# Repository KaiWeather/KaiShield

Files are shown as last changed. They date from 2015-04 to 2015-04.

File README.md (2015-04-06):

# KaiShield
Arduino Shield with capabilities of being a independent entity with a XBee.

PCB files for KaiShield for Arduino

Format is EagleCAD schematic and board layout

Designed by Kai Weather.  
Creative Commons Attribution, Share-Alike license, check license.txt for more information
All text above must be included in any redistribution

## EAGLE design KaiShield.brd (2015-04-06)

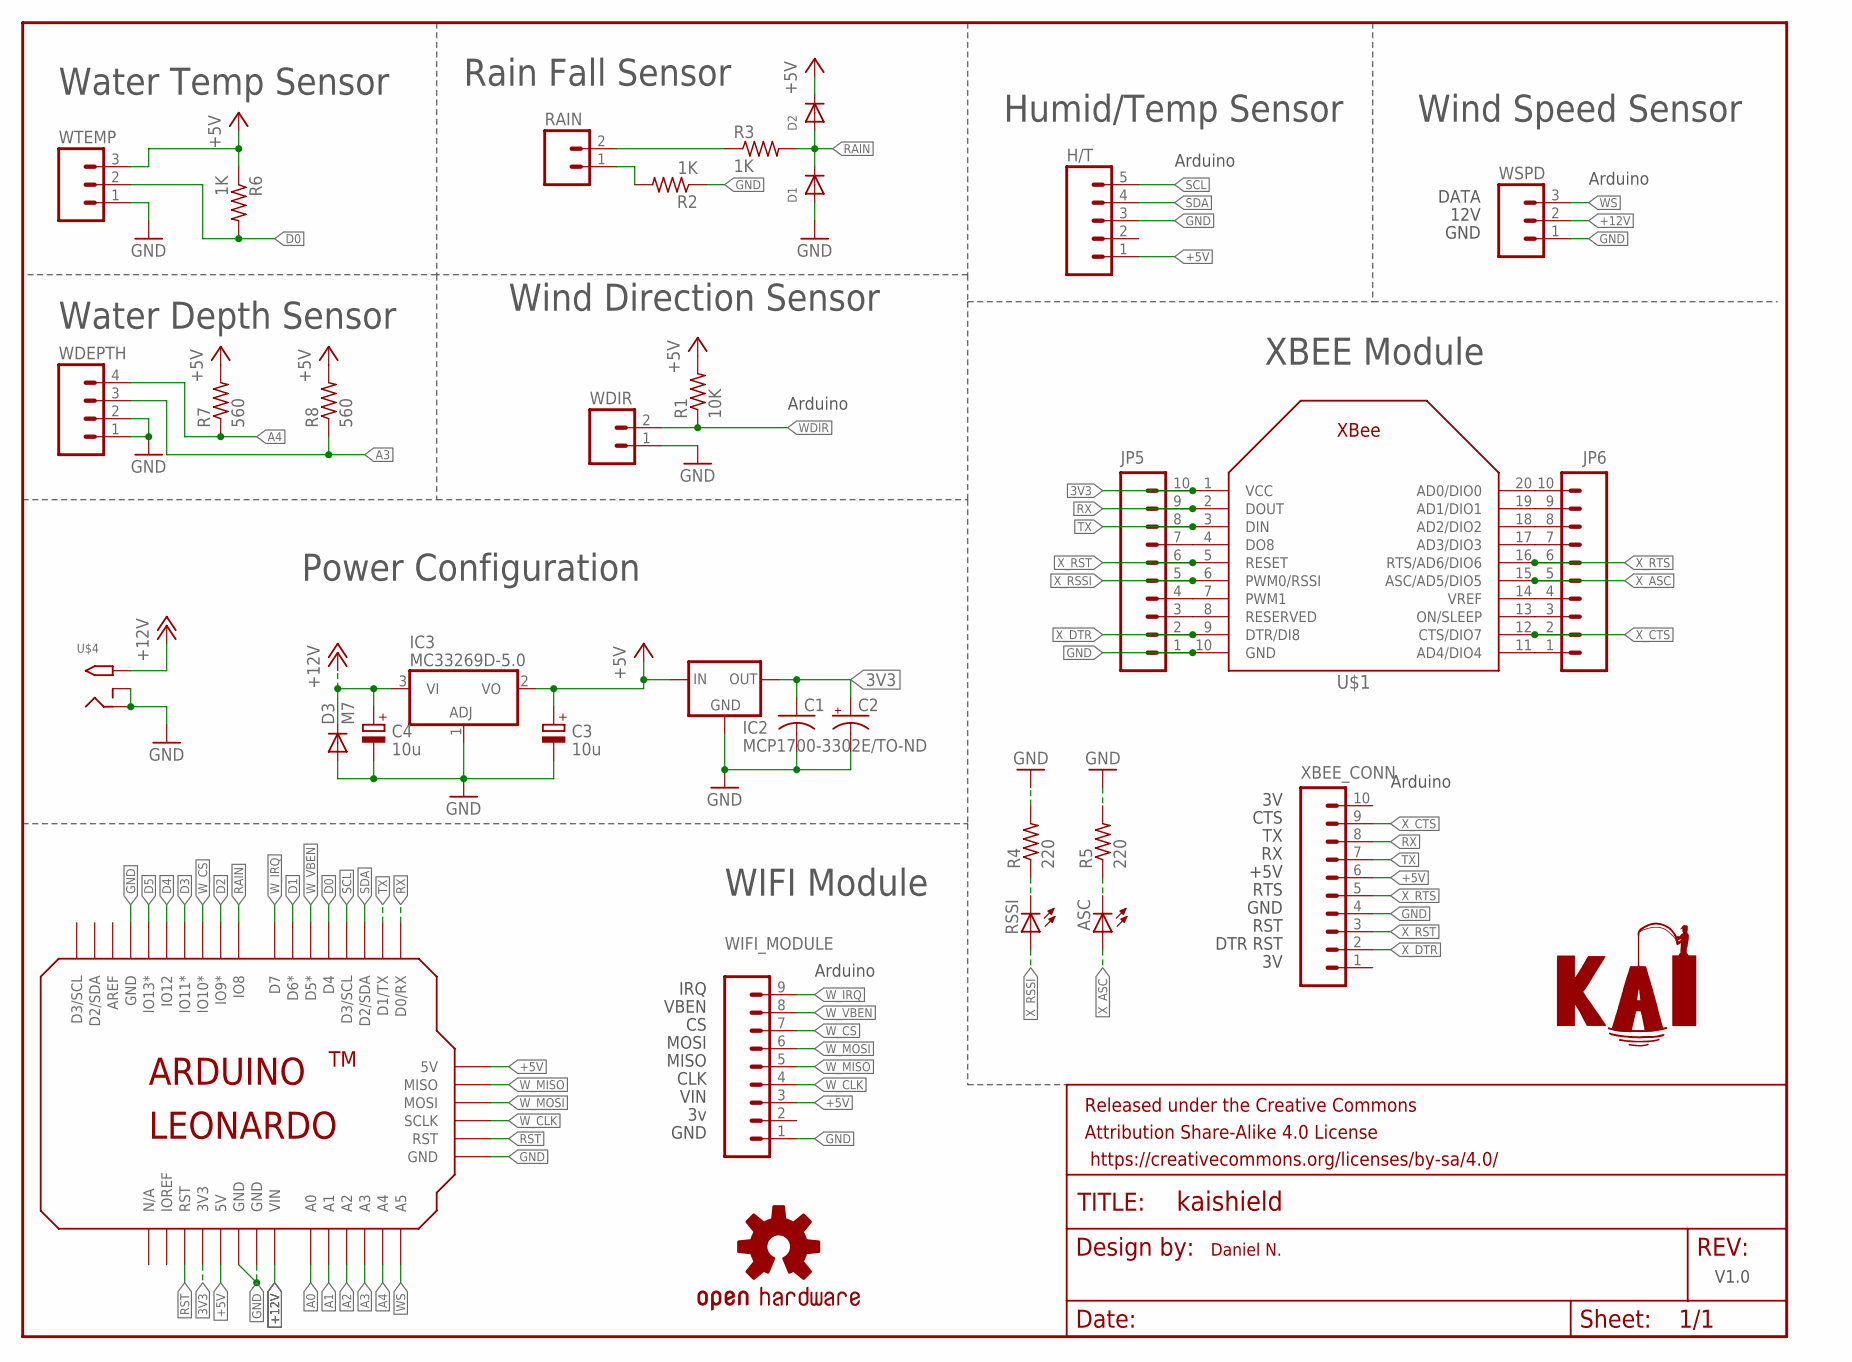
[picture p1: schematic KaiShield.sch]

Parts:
ASC: LED3MM
C1: C-US025-025X050; C025-025X050
C2: CPOL-USE2.5-5; E2,5-5
C3, C4: 10u; SMC_B
D1, D2: DIODEDO-1N4148; DO-1N4148
D3: M7; SMB
FRAME1: FRAME-LETTERNO_PACKAGE; DUMMY
H/T: M05PTH; 1X05
IC2: MCP1700-3302E/TO-ND; TO92
IC3: MC33269D-5.0; DPACK
JP5, JP6: M10SILK_FEMALE_PTH; 1X10
LOGO1: OSHW-LOGOM; OSHW-LOGO-M
R1: 10K; 0207/10
R2, R3, R6: 1K; 0207/10
R4, R5: 220; 0207/10
R7, R8: 560; 0207/10
RAIN: M02PTH; 1X02
RSSI: LED3MM
U$1: XBEE
U$2: LEONARDO
U$3: KAI_LOGO
U$4: 2.1MMJACKTHM; PJ-102A
WDEPTH: M04PTH; 1X04
WDIR: M02PTH; 1X02
WIFI_MODULE: M09; 1X09
WSPD: M03PTH; 1X03
WTEMP: M03PTH; 1X03
XBEE_CONN: M10SILK_FEMALE_PTH; 1X10

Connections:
3V3: C1.1, C2.+, IC2.3 (OUT), JP5.10, U$1.1 (VCC), U$2.3V (3V3)
+5V: C3.+, D2.C, H/T.1, IC2.2 (IN), IC3.2 (VO), R1.2, R6.1, R7.2, R8.2, U$2.5V, U$2.5V@1 (5V), WIFI_MODULE.3, WTEMP.3, XBEE_CONN.6
+12V: C4.+, D3.C, IC3.3 (VI), U$2.VIN, U$4.TIP, WSPD.2
A0: U$2.A0
A1: U$2.A1
A2: U$2.A2
A3: R8.1, U$2.A3, WDEPTH.3
A4: R7.1, U$2.A4, WDEPTH.4
D0: R6.2, U$2.D4, WTEMP.2
D1: U$2.D6 (D6*)
D2: U$2.D9 (IO9*)
D3: U$2.D11 (IO11*)
D4: U$2.D12 (IO12)
D5: U$2.D13 (IO13*)
GND: C1.2, C2.-, C3.-, C4.-, D1.A, D3.A, H/T.3, IC2.1 (GND), IC3.1 (ADJ), JP5.1, R2.1, R4.2, R5.2, U$1.10 (GND), U$2.GND, U$2.GND1 (GND), U$2.GND2 (GND), U$2.GND3 (GND), U$4.RING, U$4.RING_SW, WDEPTH.1, WDEPTH.2, WDIR.1, WIFI_MODULE.1, WSPD.1, WTEMP.1, XBEE_CONN.4
unnamed: R3.1, RAIN.2
unnamed: JP6.4, U$1.14 (VREF)
unnamed: R2.2, RAIN.1
unnamed: JP6.3, U$1.13 (ON/SLEEP)
unnamed: R4.1, RSSI.K (C)
unnamed: ASC.K (C), R5.1
unnamed: JP5.7, U$1.4 (DO8)
unnamed: JP5.4, U$1.7 (PWM1)
unnamed: JP5.3, U$1.8 (RESERVED)
RAIN: D1.C, D2.A, R3.2, U$2.D8 (IO8)
RST: U$2.RST, U$2.RST. (RST)
RX: JP5.9, U$1.2 (DOUT), U$2.D0 (D0/RX), XBEE_CONN.8
SCL: H/T.5, U$2.D3SCL (D3/SCL)
SDA: H/T.4, U$2.D2SDA (D2/SDA)
TX: JP5.8, U$1.3 (DIN), U$2.D1 (D1/TX), XBEE_CONN.7
WDIR: R1.1, WDIR.2
WS: U$2.A5, WSPD.3
W_CLK: U$2.SCLK, WIFI_MODULE.4
W_CS: U$2.D10 (IO10*), WIFI_MODULE.7
W_IRQ: U$2.D7, WIFI_MODULE.9
W_MISO: U$2.MISO, WIFI_MODULE.5
W_MOSI: U$2.MOSI, WIFI_MODULE.6
W_VBEN: U$2.D5 (D5*), WIFI_MODULE.8
X0: JP6.10, U$1.20 (AD0/DIO0)
X1: JP6.9, U$1.19 (AD1/DIO1)
X2: JP6.8, U$1.18 (AD2/DIO2)
X3: JP6.7, U$1.17 (AD3/DIO3)
X4: JP6.1, U$1.11 (AD4/DIO4)
X_ASC: ASC.A, JP6.5, U$1.15 (ASC/AD5/DIO5)
X_CTS: JP6.2, U$1.12 (CTS/DIO7), XBEE_CONN.9
X_DTR: JP5.2, U$1.9 (DTR/DI8), XBEE_CONN.2
X_RSSI: JP5.5, RSSI.A, U$1.6 (PWM0/RSSI)
X_RST: JP5.6, U$1.5 (RESET), XBEE_CONN.3
X_RTS: JP6.6, U$1.16 (RTS/AD6/DIO6), XBEE_CONN.5

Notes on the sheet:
Daniel N.
V1.0
XBEE Module
WIFI Module
RTS
+5V
CTS
GND
RST
DTR RST
VIN
CLK
MISO
MOSI
VBEN
IRQ
Humid/Temp Sensor
Wind Speed Sensor
12V
DATA
Rain Fall Sensor
Wind Direction Sensor
Arduino
Power Configuration
Water Temp Sensor
Water Depth Sensor

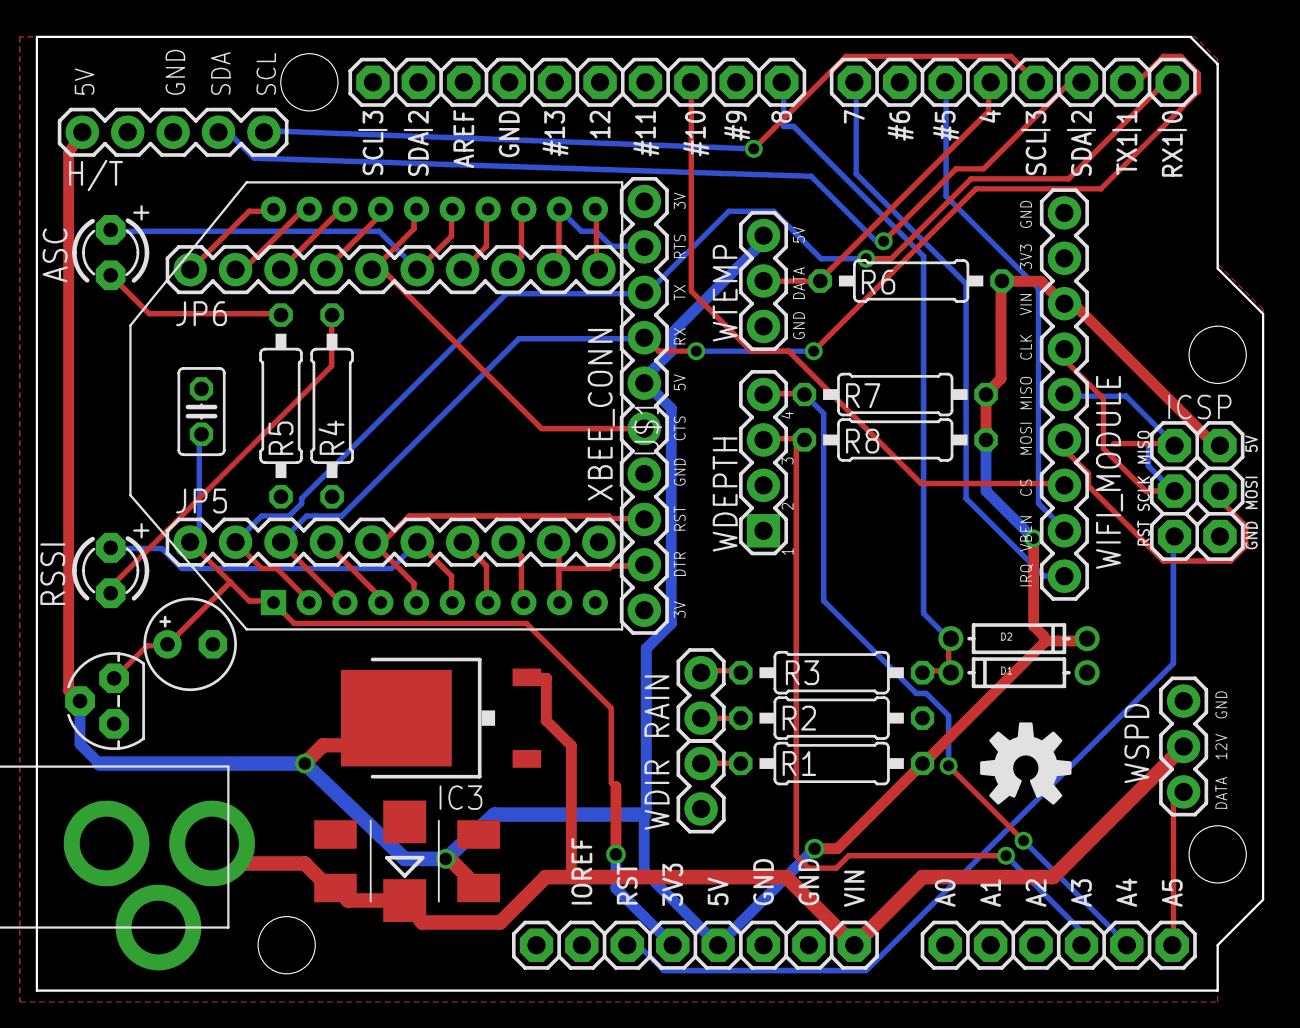
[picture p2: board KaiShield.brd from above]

Board: 2 copper layers, 68.6 x 53.3 mm, 35 parts (1 on the bottom side), 41 nets.

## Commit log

2015-04-06 Added KaiShield Version 1.0
    [KaiShield.brd, KaiShield.sch]
2015-04-06 Updated KaiShield board and added two more sensors. Now this is the main board instead of just a station board :D.
    [KaiShield.brd, KaiShield.sch]
2015-04-06 updated KaiShield with the new power ic foot print DPAK
    [KaiShield.brd, KaiShield.sch]

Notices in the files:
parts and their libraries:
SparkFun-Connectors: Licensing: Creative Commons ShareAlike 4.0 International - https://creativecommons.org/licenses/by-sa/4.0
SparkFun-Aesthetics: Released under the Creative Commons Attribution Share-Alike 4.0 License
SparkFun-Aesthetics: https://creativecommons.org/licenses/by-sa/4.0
